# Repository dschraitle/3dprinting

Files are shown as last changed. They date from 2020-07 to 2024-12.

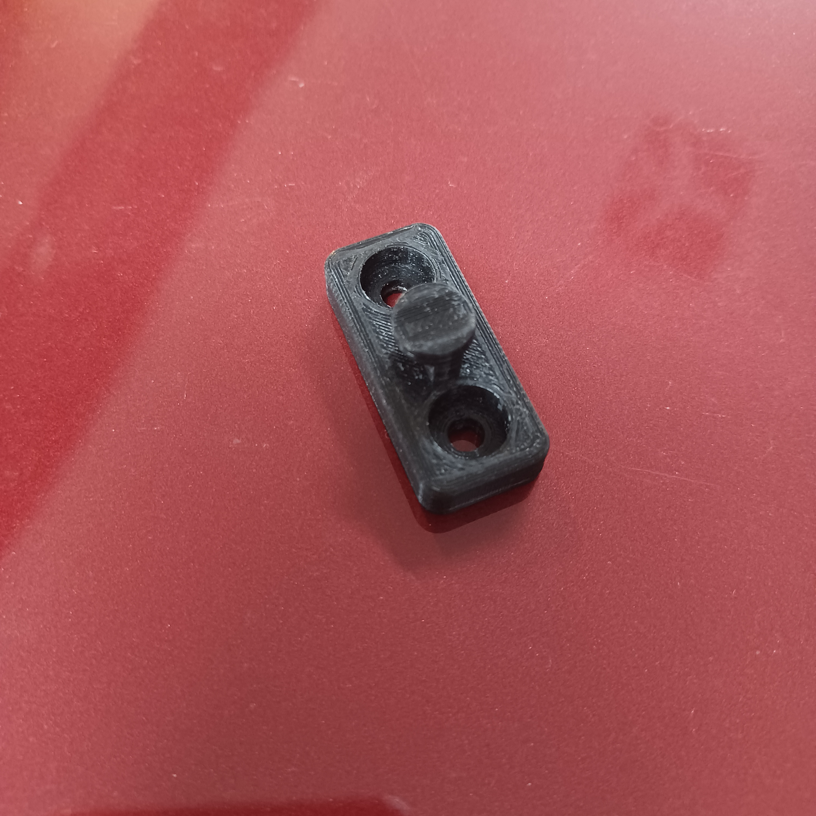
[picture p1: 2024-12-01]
designs/radio_hook/20241201_135605.jpg

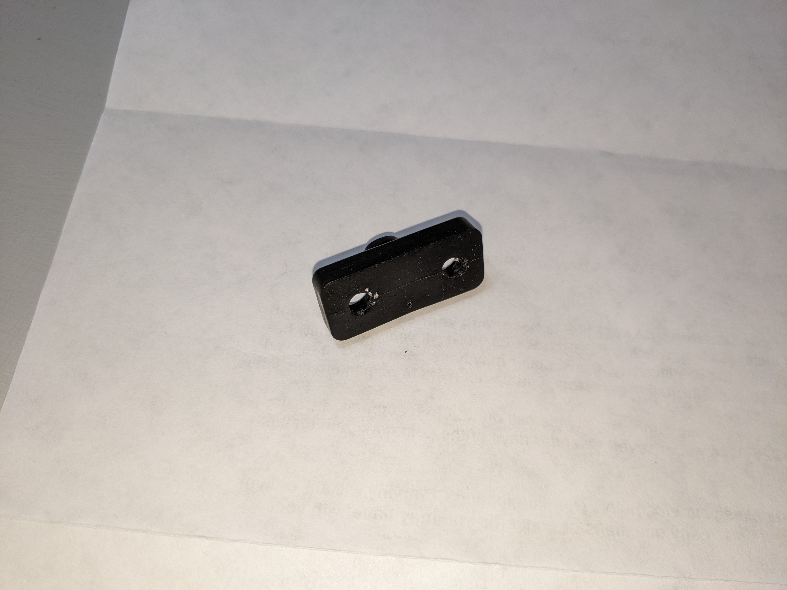
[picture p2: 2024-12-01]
designs/radio_hook/reference/PXL_20210319_022249950.jpg

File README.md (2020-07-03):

# 3dprinting
My settings and files used in my 3d printing endeavors

Thingiverse profile: https://www.thingiverse.com/schraitle

# Upgrades
- X-belt tensioner: https://www.thingiverse.com/thing:1683070
  * Having a tight x-belt made all the difference in the world. I actually had to manually tighten it before I could even print this tensioner. Before tightening it down, I couldn't create good circles and it prevented me from making a lot of other upgrades.
- Y-belt tensioner: https://www.thingiverse.com/thing:1959208
- Front frame brace: https://www.thingiverse.com/thing:1857991
- T-corner brace: https://www.thingiverse.com/thing:1672959
- Centered fan duct: https://www.thingiverse.com/thing:1620630
- Wingnut knobs: https://www.thingiverse.com/thing:2000216
  * they really are pretty useful
- Bed spring washers: https://www.thingiverse.com/thing:1895223
  * seemed like a waste of time, I'm not sure if they actually make anything better, but they do keep the springs straight
- Extruder button: https://www.thingiverse.com/thing:1935151
- Offset Y Belt Holder - https://www.thingiverse.com/thing:3085862
- X Belt Holder - https://www.thingiverse.com/thing:2016779
- X Cable Guide - https://www.thingiverse.com/thing:3852355
- Scrap Catch Tray - https://www.prusaprinters.org/prints/17835-anet-a8-scrap-catch-tray
- Z Height Jig - https://www.thingiverse.com/thing:2538266
  * useful to use every once in a while to make sure the gantry is level

# Planned upgrades

# Installed hardware
- Solid Polymer bearing replacement: https://www.amazon.com/gp/product/B06XPRCMJS
- MOSFET: https://www.amazon.com/gp/product/B01HEQVQAK
- Raspberry Pi 3B+: https://www.amazon.com/gp/product/B07BDR5PDW
  * installed octopi on it: https://octoprint.org/download/
- fiber reinforced belts - https://www.amazon.com/gp/product/B071K8HYB4
- auto bed leveler - https://www.amazon.com/gp/product/B073XC5T7B
  * using https://3dprint.wiki/reprap/anet/a8/improvement/autobedleveling#sensor_support for reference
  * will require sensor support for extruder: https://www.thingiverse.com/thing:1911146
  * also requires a wiring connector which I don't have: https://www.amazon.com/gp/product/B01M28QHF7
  * and need to rethink the cooling duct because most won't fit anymore due to the sensor support.
- PEI bed surface - https://www.amazon.com/dp/B07695DLL9/
  * Initial concern was that the extra thickness would interfere with bed leveling. It isn't an issue though, and leveling still works great.
- Wall mounted spool holder
  * Made from a closet rod set from Home Depot, holds a bunch of spools and works great.
  * Custom printed endcaps for the pipes so that the spools can't fall off.
    * https://www.prusaprinters.org/prints/20110-closet-rod-endcap
  
# Software
- Modeling: https://www.autodesk.com/products/fusion-360/overview
  * free for hobbyists, tons of youtube videos and tutorials online 
- Slicing: https://ultimaker.com/en/products/ultimaker-cura-software
- Marlin: http://marlinfw.org/
  * using the a8 example configuration with auto bed leveling set with the PROBE_MANUALLY flag
- Klipper: installed Klipper and am using the config file in klipper/printer.cfg

# Unused upgrades
- Filament guide: https://www.thingiverse.com/thing:1764285
  * I printed it draft, and it was very scratchy sounding while filament was going through so I took it off. I also didn't like how filament could get stuck in the gap for loading filament into the loop.
- X cable chain - https://www.thingiverse.com/thing:2104821
  * noticed that the cable stretching over the top of the frame caused the ABL to misread on the left side, need a solution for cable stretching, cable chain seems good
    - abandoned the cable chain, it was flexing the ABL cable too much and causing inconsistent leveling. I'll look further into better ways to hang the cable over the top of the frame
  * motor mount doesn't need to have a z endstop, will use this one - https://www.thingiverse.com/thing:2055872
- Universal spool holder: https://www.thingiverse.com/thing:767317
- Top mounted spool holder: https://www.thingiverse.com/thing:2162266
  * a little wobbly, I've read that top mounted spools create instability on the frame so we'll see how it goes. It saves desk space though, so I'm keeping it for now.
  * it actually moves laterally quite a bit, I tried to make a brace for it but I don't think it's going to help

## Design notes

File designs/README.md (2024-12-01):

just storing my designs here, I'll try to include pictures, fusion exports, printables.com links, as well as the printable models for each thing

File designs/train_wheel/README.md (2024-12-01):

train wheel to replace a broken one on this Thomas set

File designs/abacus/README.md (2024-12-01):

an abacus that you can change in fusion to have as many rows or beads as you'd like

used a 5mm wooden dowel rod to hold the beads and superglued it in

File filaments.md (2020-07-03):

# Filaments

- Shaxon PLA Red: https://www.frys.com/product/8023674
- Hatchbox PLA Blue: https://www.amazon.com/gp/product/B00J0GPC80
- Hatchbox PLA Green: https://www.amazon.com/dp/B00J0GQ2OS
  - Temp: 200 (even higher is probably better)
  - Initial Temp: 210:
  - Initial layer speed with small holes: 15 - it sucks at sticking to the bed, going slow is the only way to get it adhered

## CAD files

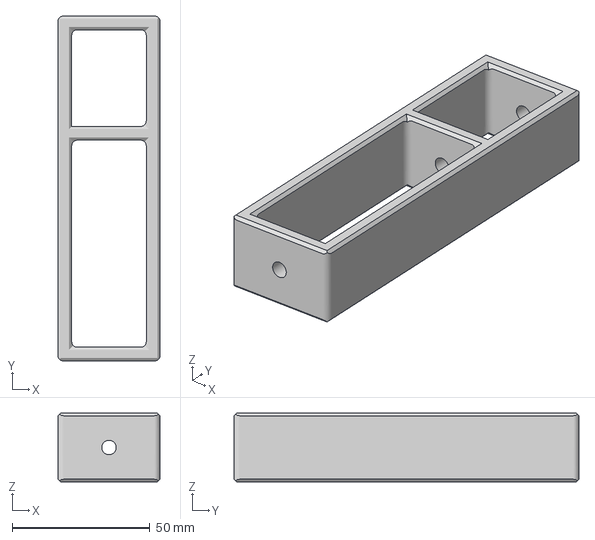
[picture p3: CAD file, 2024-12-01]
designs/abacus/onecolumn.3mf
37.0 x 125.0 x 25.0 mm

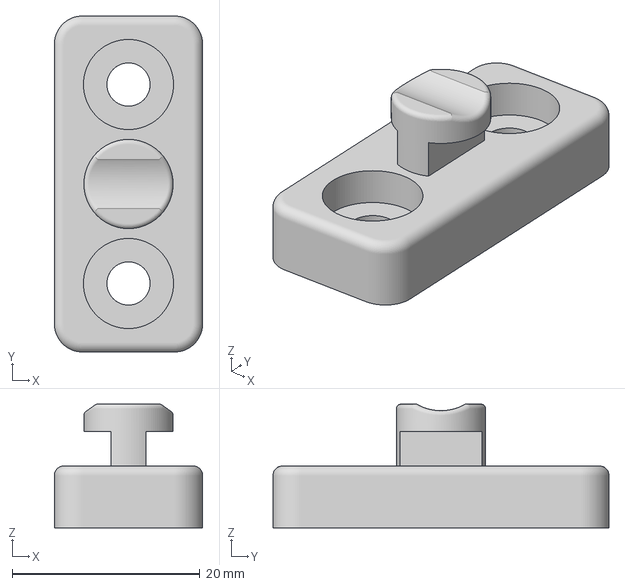
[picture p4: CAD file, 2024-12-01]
designs/radio_hook/Ford Radio Handset Hook v2.3mf
15.8 x 35.8 x 13.2 mm

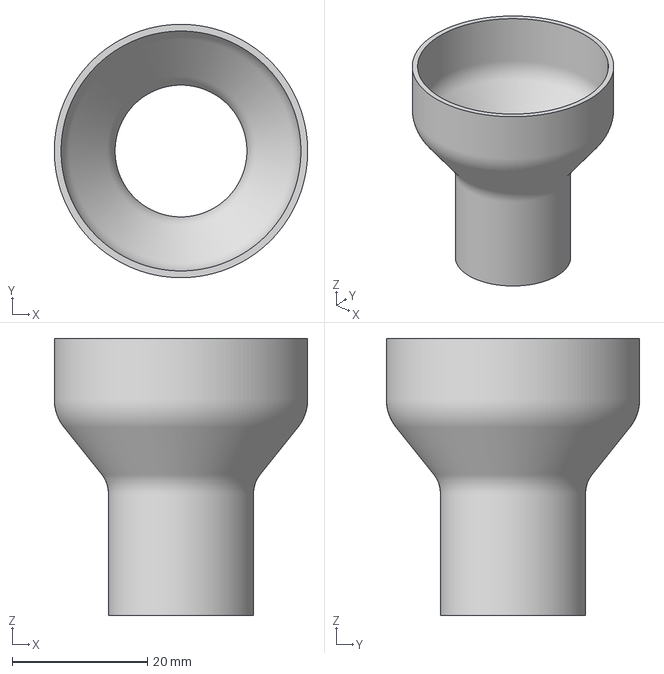
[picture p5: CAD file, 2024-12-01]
designs/soap_drainer/Soap Drainer v2.3mf
37.5 x 37.5 x 41.0 mm

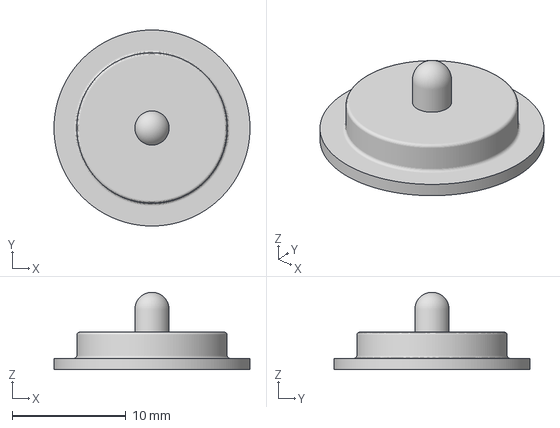
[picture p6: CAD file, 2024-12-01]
designs/train_wheel/wheel.3mf
17.2 x 17.2 x 6.80 mm

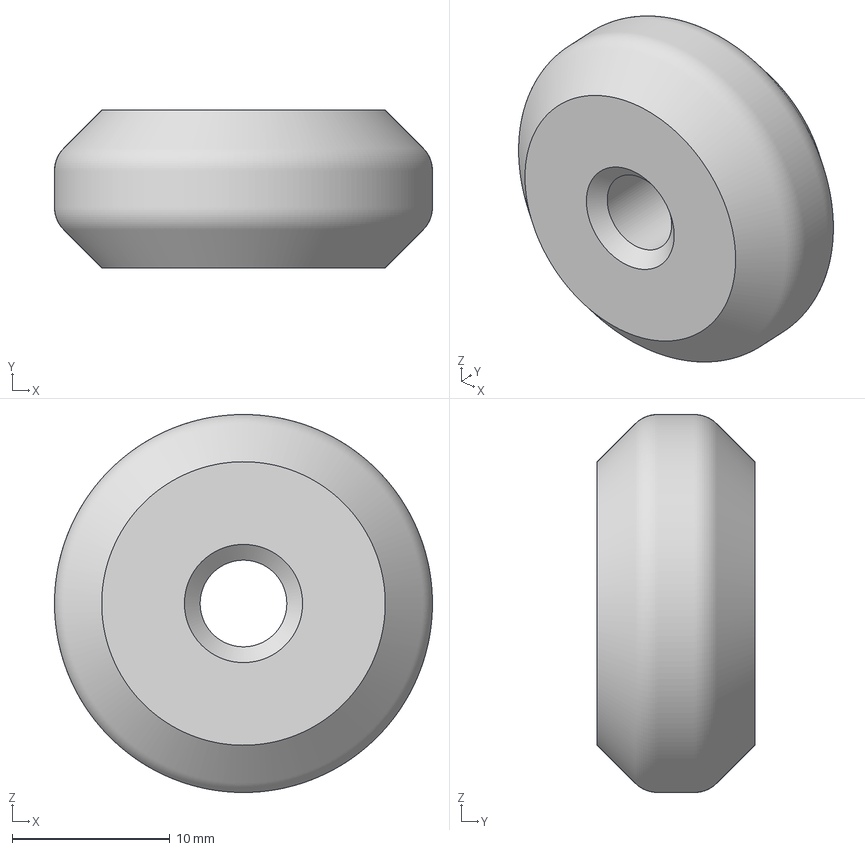
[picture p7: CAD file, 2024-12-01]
designs/abacus/bead.3mf
24.0 x 10.0 x 24.0 mm

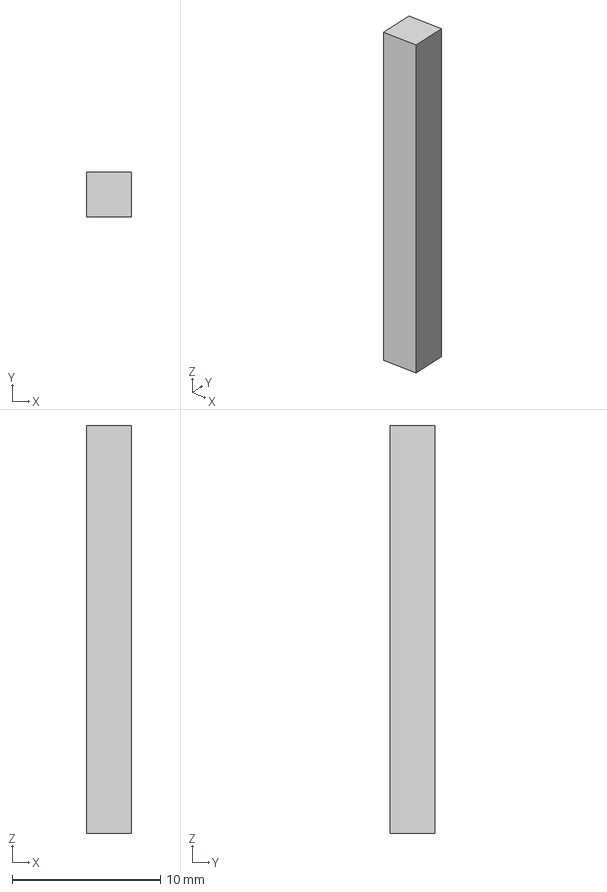
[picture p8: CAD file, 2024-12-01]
designs/train_wheel/pin.3mf
3.00 x 3.00 x 27.5 mm

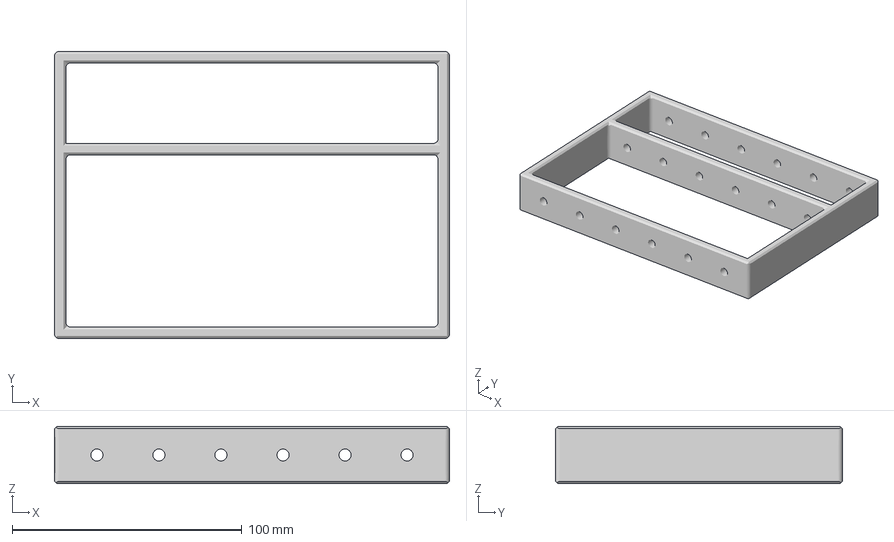
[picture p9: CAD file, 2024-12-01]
designs/abacus/6columnframe.3mf
172.0 x 125.0 x 25.0 mm

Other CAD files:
designs/abacus/Abacus.f3d
designs/radio_hook/Ford Radio Handset Hook v2.f3d
designs/soap_drainer/Soap Drainer v2.f3d
designs/train_wheel/thomas_train_car_wheel v8.f3d

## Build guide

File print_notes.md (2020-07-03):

#### Swiss army SD card holder - https://www.thingiverse.com/thing:633436
  - I printed at 106% and it was just a hair too big for micro SD cards, going to print the next microSD slice at 105%
  - SD test printed best at 102%

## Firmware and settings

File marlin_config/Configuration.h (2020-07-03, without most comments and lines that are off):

#define CONFIGURATION_H
#define CONFIGURATION_H_VERSION 010109
#define STRING_CONFIG_H_AUTHOR "(Bob Kuhn, Anet config)" // Who made the changes.
#define SHOW_BOOTSCREEN
#define STRING_SPLASH_LINE1 SHORT_BUILD_VERSION // will be shown during bootup in line 1
#define STRING_SPLASH_LINE2 WEBSITE_URL         // will be shown during bootup in line 2
#define SERIAL_PORT 0
#define BAUDRATE 115200
  #define MOTHERBOARD BOARD_ANET_10
#define EXTRUDERS 1
#define DEFAULT_NOMINAL_FILAMENT_DIA 1.75
#define POWER_SUPPLY 0
#define TEMP_SENSOR_0 5
#define TEMP_SENSOR_1 0
#define TEMP_SENSOR_2 0
#define TEMP_SENSOR_3 0
#define TEMP_SENSOR_4 0
#define TEMP_SENSOR_BED 5
#define TEMP_SENSOR_CHAMBER 0
#define DUMMY_THERMISTOR_998_VALUE 25
#define DUMMY_THERMISTOR_999_VALUE 100
#define MAX_REDUNDANT_TEMP_SENSOR_DIFF 10
#define TEMP_RESIDENCY_TIME 6   // (seconds)
#define TEMP_HYSTERESIS 3       // (degC) range of +/- temperatures considered "close" to the target one
#define TEMP_WINDOW     1       // (degC) Window around target to start the residency timer x degC early.
#define TEMP_BED_RESIDENCY_TIME 6   // (seconds)
#define TEMP_BED_HYSTERESIS 3       // (degC) range of +/- temperatures considered "close" to the target one
#define TEMP_BED_WINDOW     1       // (degC) Window around target to start the residency timer x degC early.
#define HEATER_0_MINTEMP 5
#define HEATER_1_MINTEMP 5
#define HEATER_2_MINTEMP 5
#define HEATER_3_MINTEMP 5
#define HEATER_4_MINTEMP 5
#define BED_MINTEMP 5
#define HEATER_0_MAXTEMP 275
#define HEATER_1_MAXTEMP 275
#define HEATER_2_MAXTEMP 275
#define HEATER_3_MAXTEMP 275
#define HEATER_4_MAXTEMP 275
#define BED_MAXTEMP 130
#define PIDTEMP
#define BANG_MAX 255     // Limits current to nozzle while in bang-bang mode; 255=full current
#define PID_MAX BANG_MAX // Limits current to nozzle while PID is active (see PID_FUNCTIONAL_RANGE below); 255=full current
#define PID_K1 0.95      // Smoothing factor within any PID loop
  #define PID_FUNCTIONAL_RANGE 15 // If the temperature difference between the target temperature and the actual temperature
  #define DEFAULT_Kp 21.0
  #define DEFAULT_Ki 1.25
  #define DEFAULT_Kd 86.0
#define PIDTEMPBED
#define MAX_BED_POWER 255 // limits duty cycle to bed; 255=full current
  #define DEFAULT_bedKp 10.00
  #define DEFAULT_bedKi .023
  #define DEFAULT_bedKd 305.4
#define PREVENT_COLD_EXTRUSION
#define EXTRUDE_MINTEMP 160  // 160 guards against false tripping when the extruder fan kicks on.
#define PREVENT_LENGTHY_EXTRUDE
#define EXTRUDE_MAXLENGTH 200
#define THERMAL_PROTECTION_HOTENDS // Enable thermal protection for all extruders
#define THERMAL_PROTECTION_BED     // Enable thermal protection for the heated bed
#define USE_XMIN_PLUG
#define USE_YMIN_PLUG
#define USE_ZMIN_PLUG
#define ENDSTOPPULLUPS
#define X_MIN_ENDSTOP_INVERTING true  // set to true to invert the logic of the endstop.
#define Y_MIN_ENDSTOP_INVERTING true  // set to true to invert the logic of the endstop.
#define Z_MIN_ENDSTOP_INVERTING true  // set to true to invert the logic of the endstop.
#define X_MAX_ENDSTOP_INVERTING false // set to true to invert the logic of the endstop.
#define Y_MAX_ENDSTOP_INVERTING false // set to true to invert the logic of the endstop.
#define Z_MAX_ENDSTOP_INVERTING false // set to true to invert the logic of the endstop.
#define Z_MIN_PROBE_ENDSTOP_INVERTING true  // set to true to invert the logic of the probe.
#define ENDSTOP_INTERRUPTS_FEATURE
#define DEFAULT_AXIS_STEPS_PER_UNIT   { 100, 100, 400, 100 }
#define DEFAULT_MAX_FEEDRATE          { 400, 400, 8, 50 }
#define DEFAULT_MAX_ACCELERATION      { 2000, 2000, 100, 10000 }
#define DEFAULT_ACCELERATION          400     // X, Y, Z and E acceleration for printing moves
#define DEFAULT_RETRACT_ACCELERATION  1000    // E acceleration for retracts
#define DEFAULT_TRAVEL_ACCELERATION   1000    // X, Y, Z acceleration for travel (non printing) moves
#define DEFAULT_XJERK                 10.0
#define DEFAULT_YJERK                 10.0
#define DEFAULT_ZJERK                  0.3
#define DEFAULT_EJERK                  5.0
#define Z_MIN_PROBE_USES_Z_MIN_ENDSTOP_PIN
#define FIX_MOUNTED_PROBE
#define X_PROBE_OFFSET_FROM_EXTRUDER 65   // X offset: -left  +right  [of the nozzle]
#define Y_PROBE_OFFSET_FROM_EXTRUDER -36   // Y offset: -front +behind [the nozzle]
#define Z_PROBE_OFFSET_FROM_EXTRUDER 2   // Z offset: -below +above  [the nozzle]
#define MIN_PROBE_EDGE 20
#define XY_PROBE_SPEED 6000
#define Z_PROBE_SPEED_FAST HOMING_FEEDRATE_Z
#define Z_PROBE_SPEED_SLOW (Z_PROBE_SPEED_FAST / 2)
#define MULTIPLE_PROBING 4
#define Z_CLEARANCE_DEPLOY_PROBE   10 // Z Clearance for Deploy/Stow
#define Z_CLEARANCE_BETWEEN_PROBES  5 // Z Clearance between probe points
#define Z_CLEARANCE_MULTI_PROBE     5 // Z Clearance between multiple probes
#define Z_PROBE_LOW_POINT          -2 // Farthest distance below the trigger-point to go before stopping
#define Z_PROBE_OFFSET_RANGE_MIN -20
#define Z_PROBE_OFFSET_RANGE_MAX 20
#define Z_MIN_PROBE_REPEATABILITY_TEST
#define X_ENABLE_ON 0
#define Y_ENABLE_ON 0
#define Z_ENABLE_ON 0
#define E_ENABLE_ON 0 // For all extruders
#define DISABLE_X false
#define DISABLE_Y false
#define DISABLE_Z false
#define DISABLE_E false // For all extruders
#define DISABLE_INACTIVE_EXTRUDER true // Keep only the active extruder enabled.
#define INVERT_X_DIR false
#define INVERT_Y_DIR false
#define INVERT_Z_DIR true
#define INVERT_E0_DIR false
#define INVERT_E1_DIR false
#define INVERT_E2_DIR false
#define INVERT_E3_DIR false
#define INVERT_E4_DIR false
#define X_HOME_DIR -1
#define Y_HOME_DIR -1
#define Z_HOME_DIR -1
#define X_BED_SIZE 220
#define Y_BED_SIZE 220
#define X_MIN_POS -33
#define Y_MIN_POS -10
#define Z_MIN_POS 0
#define X_MAX_POS X_BED_SIZE
#define Y_MAX_POS Y_BED_SIZE
#define Z_MAX_POS 240
#define MIN_SOFTWARE_ENDSTOPS
  #define MIN_SOFTWARE_ENDSTOP_X
  #define MIN_SOFTWARE_ENDSTOP_Y
  #define MIN_SOFTWARE_ENDSTOP_Z
#define MAX_SOFTWARE_ENDSTOPS
  #define MAX_SOFTWARE_ENDSTOP_X
  #define MAX_SOFTWARE_ENDSTOP_Y
  #define MAX_SOFTWARE_ENDSTOP_Z
#define AUTO_BED_LEVELING_BILINEAR
#define RESTORE_LEVELING_AFTER_G28
  #define ENABLE_LEVELING_FADE_HEIGHT
  #define SEGMENT_LEVELED_MOVES
  #define LEVELED_SEGMENT_LENGTH 5.0 // (mm) Length of all segments (except the last one)
  #define GRID_MAX_POINTS_X 5
  #define GRID_MAX_POINTS_Y GRID_MAX_POINTS_X
  #define LEFT_PROBE_BED_POSITION 35
  #define RIGHT_PROBE_BED_POSITION 200
  #define BACK_PROBE_BED_POSITION 180
  #define FRONT_PROBE_BED_POSITION 20
#define LCD_BED_LEVELING
  #define MBL_Z_STEP 0.025    // Step size while manually probing Z axis.
  #define LCD_PROBE_Z_RANGE 4 // Z Range centered on Z_MIN_POS for LCD Z adjustment
#define Z_SAFE_HOMING
  #define Z_SAFE_HOMING_X_POINT ((X_BED_SIZE) / 2)    // X point for Z homing when homing all axes (G28).
  #define Z_SAFE_HOMING_Y_POINT ((Y_BED_SIZE) / 2)    // Y point for Z homing when homing all axes (G28).
#define HOMING_FEEDRATE_XY (100*60)
#define HOMING_FEEDRATE_Z  (4*60)
#define EEPROM_SETTINGS   // Enable for M500 and M501 commands
#define EEPROM_CHITCHAT   // Give feedback on EEPROM commands. Disable to save PROGMEM.
#define BUSY_WHILE_HEATING            // Some hosts require "busy" messages even during heating
#define PREHEAT_1_TEMP_HOTEND 190
#define PREHEAT_1_TEMP_BED     60
#define PREHEAT_1_FAN_SPEED     0 // Value from 0 to 255
#define PREHEAT_2_TEMP_HOTEND 240
#define PREHEAT_2_TEMP_BED     90
#define PREHEAT_2_FAN_SPEED     0 // Value from 0 to 255
#define PRINTJOB_TIMER_AUTOSTART
#define LCD_LANGUAGE en
#define DISPLAY_CHARSET_HD44780 JAPANESE
#define SDSUPPORT
#define ZONESTAR_LCD              // Requires ADC_KEYPAD_PIN to be assigned to an analog pin.
#define SOFT_PWM_SCALE 0
#define SERVO_DELAY { 300 }

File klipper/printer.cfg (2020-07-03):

# This file contains common pin mappings for Anet A8 printer from 2016
# and 2017. To use this config, the firmware should be compiled for
# the AVR atmega1284p.

# Note that the "make flash" command does not work with Anet boards -
# the boards are typically flashed with this command:
#  avrdude -p atmega1284p -c arduino -b 57600 -P /dev/ttyUSB0 -U out/klipper.elf.hex

# See the example.cfg file for a description of available parameters.

[stepper_x]
step_pin: PD7
dir_pin: PC5
enable_pin: !PD6
step_distance: .01
endstop_pin: ^!PC2
position_endstop: -30
position_max: 220
position_min: -30
homing_speed: 50

[stepper_y]
step_pin: PC6
dir_pin: PC7
enable_pin: !PD6
step_distance: .01
endstop_pin: ^!PC3
position_endstop: -8
position_min: -8
position_max: 220
homing_speed: 50

[stepper_z]
step_pin: PB3
dir_pin: !PB2
enable_pin: !PA5
step_distance: .0025
#endstop_pin: ^!PC4
endstop_pin: probe:z_virtual_endstop
#position_endstop: 0.5
position_max: 240
position_min: -1
homing_speed: 20

[extruder]
step_pin: PB1
dir_pin: PB0
enable_pin: !PD6
step_distance: .0105
nozzle_diameter: 0.400
filament_diameter: 1.750
heater_pin: PD5
sensor_type: ATC Semitec 104GT-2
sensor_pin: PA7
#control: pid
#pid_Kp: 2.151492
#pid_Ki: 0.633897
#pid_Kd: 230.042965
min_temp: 0
max_temp: 250

[heater_bed]
heater_pin: PD4
sensor_type: ATC Semitec 104GT-2
sensor_pin: PA6
#control: watermark
min_temp: 0
max_temp: 130

[fan]
pin: PB4

[mcu]
#baud: 57600
serial: /dev/serial/by-id/usb-1a86_USB2.0-Serial-if00-port0	

[printer]
kinematics: cartesian
max_velocity: 300
max_accel: 1000
max_z_velocity: 20
max_z_accel: 100

[display]
lcd_type: hd44780
rs_pin: PA3
e_pin: PA2
d4_pin: PD2
d5_pin: PD3
d6_pin: PC0
d7_pin: PC1
up_pin: PA1
analog_range_up_pin: 9000, 13000
down_pin: PA1
analog_range_down_pin: 800, 1300
click_pin: PA1
analog_range_click_pin: 2000, 2500
back_pin: PA1
analog_range_back_pin: 4500, 5000
#kill_pin: PA1
#analog_range_kill_pin: 400, 600

######################################################################
# Bed probing hardware
######################################################################

# Z height probe. One may define this section to enable Z height
# probing hardware. When this section is enabled, PROBE and
# QUERY_PROBE extended g-code commands become available. The probe
# section also creates a virtual "probe:z_virtual_endstop" pin. One
# may set the stepper_z endstop_pin to this virtual pin on cartesian
# style printers that use the probe in place of a z endstop. If using
# "probe:z_virtual_endstop" then do not define a position_endstop in
# the stepper_z config section.
[probe]
pin: ^!PC4
#   Probe detection pin. This parameter must be provided.
x_offset: 65
#   The distance (in mm) between the probe and the nozzle along the
#   x-axis. The default is 0.
y_offset: -36
#   The distance (in mm) between the probe and the nozzle along the
#   y-axis. The default is 0.
#z_offset: 2
#   The distance (in mm) between the bed and the nozzle when the probe
#   triggers. This parameter must be provided.
#speed: 5.0
#   Speed (in mm/s) of the Z axis when probing. The default is 5mm/s.
#samples: 1
#   The number of times to probe each point. The probed z-values will
#   be averaged. The default is to probe 1 time.
#sample_retract_dist: 2.0
#   The distance (in mm) to lift the toolhead between each sample (if
#   sampling more than once). The default is 2mm.
#lift_speed: 5.0
#   Speed (in mm/s) of the Z axis when lifting the probe between
#   samples. The default is to use the same value as the 'speed'
#   parameter.
#samples_result: average
#   The calculation method when sampling more than once - either
#   "median" or "average". The default is average.
#samples_tolerance: 0.100
#   The maximum Z distance (in mm) that a sample may differ from other
#   samples. If this tolerance is exceeded then either an error is
#   reported or the attempt is restarted (see
#   samples_tolerance_retries). The default is 0.100mm.
samples_tolerance_retries: 1
#   The number of times to retry if a sample is found that exceeds
#   samples_tolerance. On a retry, all current samples are discarded
#   and the probe attempt is restarted. If a valid set of samples are
#   not obtained in the given number of retries then an error is
#   reported. The default is zero which causes an error to be reported
#   on the first sample that exceeds samples_tolerance.
#activate_gcode:
#   A list of G-Code commands to execute prior to each probe attempt.
#   See docs/Command_Templates.md for G-Code format. This may be
#   useful if the probe needs to be activated in some way. Do not
#   issue any commands here that move the toolhead (eg, G1). The
#   default is to not run any special G-Code commands on activation.
#deactivate_gcode:
#   A list of G-Code commands to execute after each probe attempt
#   completes. See docs/Command_Templates.md for G-Code format. Do not
#   issue any commands here that move the toolhead. The default is to
#   not run any special G-Code commands on deactivation.



######################################################################
# Bed leveling support
######################################################################

# Mesh Bed Leveling. One may define a [bed_mesh] config section
# to enable move transformations that offset the z axis based
# on a mesh generated from probed points. Note that bed_mesh
# and bed_tilt are incompatible, both cannot be defined.  When
# using a probe to home the z-axis, it is recommended to define
# a [homing_override] section in printer.cfg to home toward the
# center of the print area.
#
#  Visual Examples:
#   rectangular bed, probe_count = 3,3:
#               x---x---x (max_point)
#               |
#               x---x---x
#                       |
#   (min_point) x---x---x
#
#   round bed, round_probe_count = 5, bed_radius = r:
#                  x (0,r) end
#                /
#              x---x---x
#                        \
#   (-r,0) x---x---x---x---x (r,0)
#            \
#              x---x---x
#                    /
#                  x  (0,-r) start
#
[bed_mesh]
#speed: 50
#   The speed (in mm/s) of non-probing moves during the
#   calibration. The default is 50.
#horizontal_move_z: 5
#   The height (in mm) that the head should be commanded to move to
#   just prior to starting a probe operation. The default is 5.
#mesh_radius:
#   Defines the radius of the mesh to probe for round beds.  Note that the
#   radius is relative to the coordinate specified by the mesh_origin option.
#   This parameter must be provided for round beds and omitted for rectangular
#   beds.
#mesh_origin:
#   Defines the center x,y coordinate of the mesh for round beds.  This
#   coordinate is relative to the probe's location.  It may be useful
#   to adjust the mesh_origin in an effort to maximize the size of the
#   mesh radius.  Default is 0,0.  This parameter must be omitted for
#   rectangular beds.
mesh_min: 35,10
#   Defines the minimum x,y coodinate of the mesh for rectangular beds.  This
#   coordinate is relative to the probe's location. This will be the first
#   point probed, nearest to the origin. This parameter must be provided for
#   rectangular beds.
mesh_max: 210, 174
#   Defines the maximum x,y coordinate of the mesh for rectangular beds.
#   Adheres to the same principle as mesh_min, however this will be the
#   furthest point probed from the bed's origin. This parameter must be
#   provided for rectangular beds.
#probe_count: 3,3
#   For rectangular beds, this is a comma separate pair of integer
#   values (X,Y) defining the number of points to probe along each axis.
#   A single value is also valid, in which case that value will be applied
#   to both axes.  Default is 3,3.
#round_probe_count: 5
#   For round beds, this integer value defines the maximum number of
#   points to probe along each axis. This value must be an odd number.
#   Default is 5.
#fade_start: 1.0
#   The gcode z position in which to start phasing out z-adjustment
#   when fade is enabled.  Default is 1.0.
#fade_end: 0.0
#   The gcode z position in which phasing out completes.  When set
#   to a value below fade_start, fade is disabled. It should be
#   noted that fade may add unwanted scaling along the z-axis of a
#   print.  If a user wishes to enable fade, a value of 10.0 is
#   recommended. Default is 0.0, which disables fade.
#fade_target:
#   The z position in which fade should converge. When this value is set
#   to a non-zero value it must be within the range of z-values in the mesh.
#   Users that wish to converge to the z homing position should set this to 0.
#   Default is the average z value of the mesh.
#split_delta_z: .025
#   The amount of Z difference (in mm) along a move that will
#   trigger a split. Default is .025.
#move_check_distance: 5.0
#   The distance (in mm) along a move to check for split_delta_z.
#   This is also the minimum length that a move can be split. Default
#   is 5.0.
#mesh_pps: 2,2
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

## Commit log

2019-01-21 adding profiles from cura and a project
    [PI3_Flush_Cutter_Holder.3mf]
2019-01-21 adding marlin config
    [Configuration.h, Configuration_adv.h, universal_spool_holder.3mf]
2019-02-05 planning for auto bed leveling
2019-02-10 updating marlin config for ABL using tutorial settings
    [Configuration.h]
2019-02-10 updating config with changes made while installing ABL
    [Configuration.h]
2019-03-14 updating with profiles and machine settings via a saved cura project
    [PI3_Flush_Cutter_Holder.3mf, universal_spool_holder.3mf]
2019-03-25 move x cable chain to unused upgrades
2019-08-25 using pid tuning for bed, updating autolevel config
    [Configuration.h]
2019-08-25 adding x belt holder to upgrades
2020-02-01 Update README.md
    added closet rod endcaps
2020-07-03 adding klipper config
    [printer.cfg]
2020-07-03 updating readme with klipper config path
2024-12-01 files for soap drainer
    [Soap Drainer v2.3mf, Soap Drainer v2.f3d]
2024-12-01 Add abacus design
    commit 0de5a9fe4d7bfe416aa5d530797d3dc641f1e47b
    Author: David Schraitle <rubikscubist@gmail.com>
    Date: Sun Dec 1 13:09:23 2024 -0500
    model files and fusion export
    commit dadd1e3a15bc37386a61f51fbab71e922487bcde
    Author: David Schraitle <rubikscubist@gmail.com>
    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
    [6columnframe.3mf, Abacus.f3d, bead.3mf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]
2024-12-01 train wheel (#2)
    [pin.3mf, thomas_train_car_wheel v8.f3d, wheel.3mf]
2024-12-01 Radio hook (#1)
    * add files
    * add reference images
    * add images
    [Ford Radio Handset Hook v2.3mf, Ford Radio Handset Hook v2.f3d]

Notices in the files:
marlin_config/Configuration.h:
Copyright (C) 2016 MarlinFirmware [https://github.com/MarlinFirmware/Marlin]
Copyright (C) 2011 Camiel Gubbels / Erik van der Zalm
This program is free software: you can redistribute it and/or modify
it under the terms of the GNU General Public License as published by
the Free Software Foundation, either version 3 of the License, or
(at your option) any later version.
